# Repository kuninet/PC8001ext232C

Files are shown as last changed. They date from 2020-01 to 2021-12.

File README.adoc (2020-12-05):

= PC-8001用 外付けRS232Cボード =

== 概要 ==
* PC-8001の外部拡張バスへ接続する外付けRS232Cボードです。
** N-BASIC標準の PRINT%等のコマンドで動作することを目指します。
* シリアルLSI8251x2を搭載し、受信割り込みを使用します。

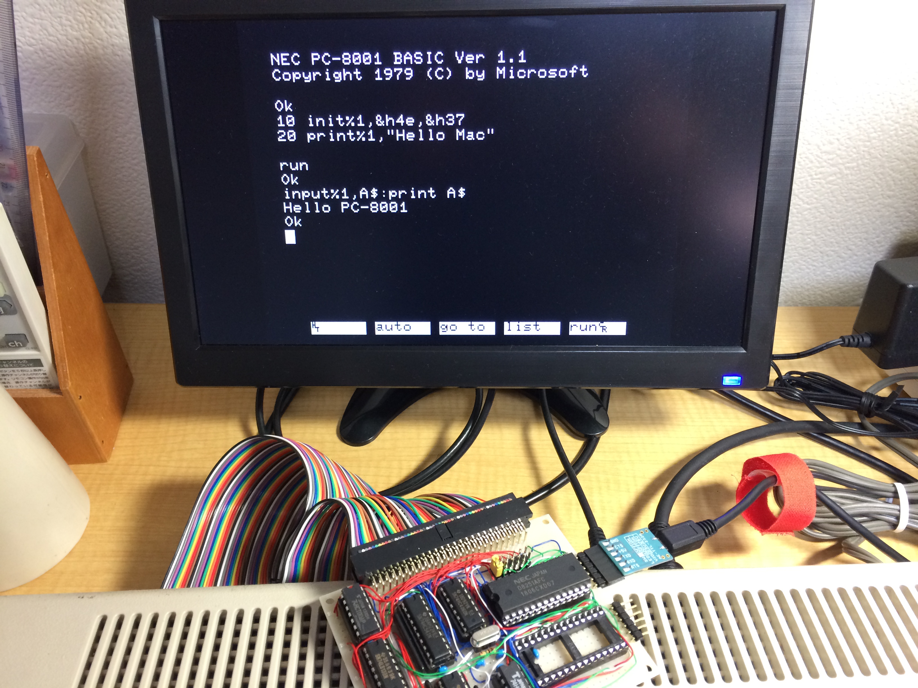
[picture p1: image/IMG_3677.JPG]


== I/Oアドレス == 
* シリアルIC 8251のI/Oアドレスは、PC-8001のPRINT%命令で動くように以下のようになっています。

.I/Oアドレス一覧
|===
|I/Oアドレス |用途 

|0C0H
|RS232C Ch1 8251データ入出力

|0C1H
|RS232C Ch1 8251コントロール入出力

|0C2H
|RS232C Ch2 8251データ入出力

|0C3H
|RS232C Ch2 8251コントロール入出力

|===

== 受信割り込みについて == 
* PC-8001はPC-8011/8012が接続された場合にモード2割り込みを使って割り込み処理をしています。割り込みベクタテーブルはPC-8001のRAM上に展開されています。
* シリアルIC 8251からの受信割り込みが発生した場合、ロジックICでモード2割り込みのベクタ08h、0Ahをデータバスに載せる仕組みを搭載しました。Z80 CPUは 8000hからの変位値として認識して 8008h、800Ah番地に格納されているRS232C処理アドレス(N-BASIC ROM内)へジャンプしてくれます。

.シリアル関係 割り込みアドレス一覧
|===
|割り込みベクタアドレス |用途 

|08008H
|RS232C Ch1 割り込みベクタ

|0800AH
|RS232C Ch2 割り込みベクタ

|===

== 参考URL == 
* Enriさんの ＰＣ－８００１ページ
** http://www43.tok2.com/home/cmpslv/Pc80/EnrPc.htm
* PC-8001 外付け232Cボード (BLOGで紹介した記事)
** https://kuninet.org/2020/01/25/pc-8001-%e5%a4%96%e4%bb%98%e3%81%91232c%e3%83%9c%e3%83%bc%e3%83%89/

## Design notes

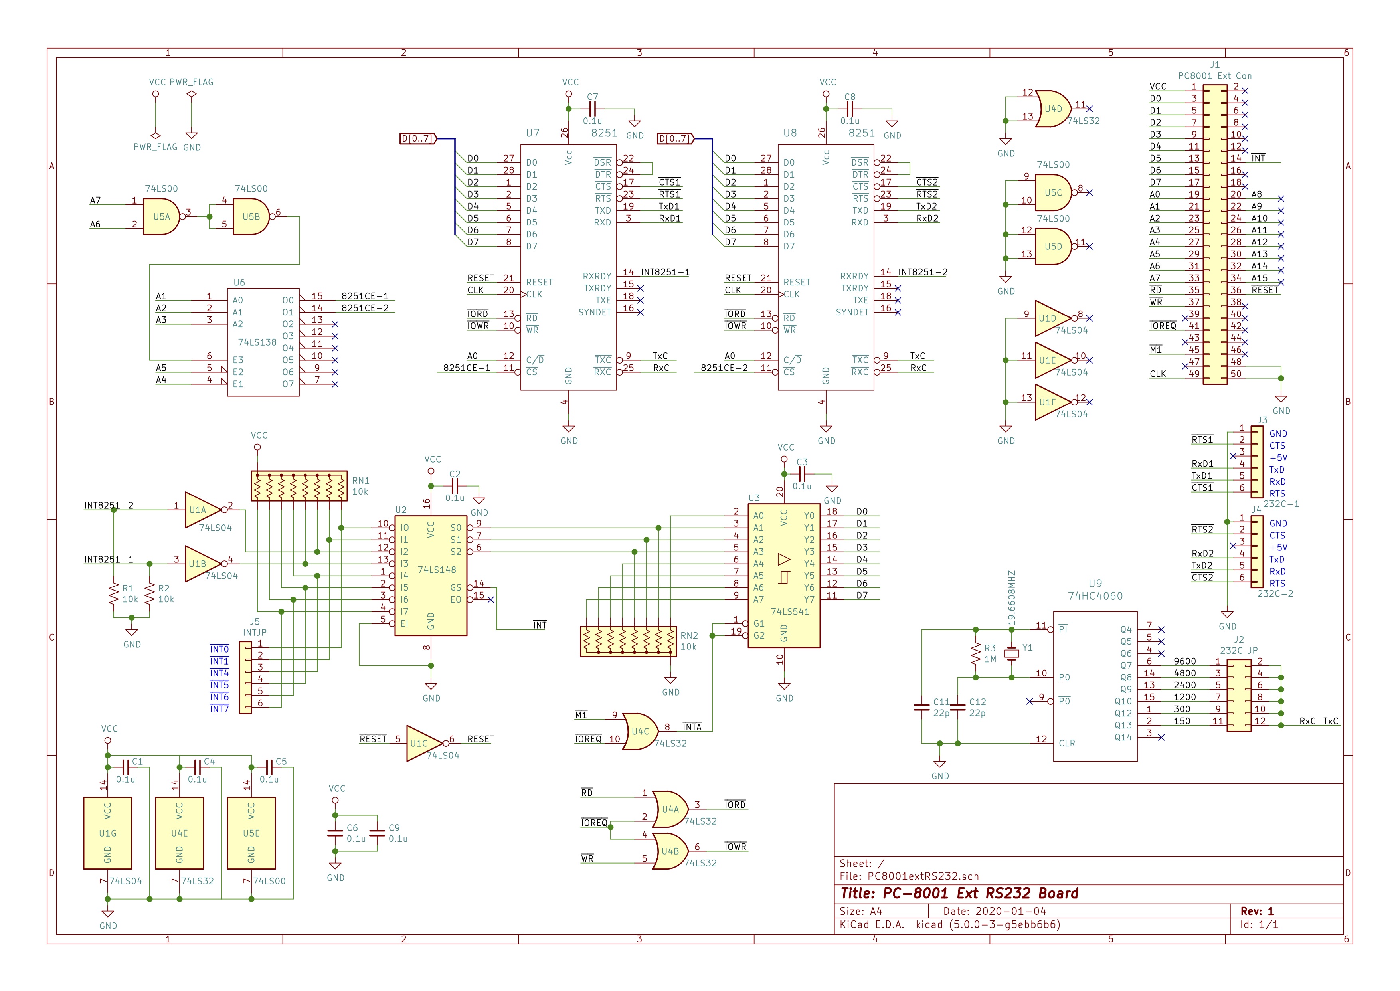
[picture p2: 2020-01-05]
image/PC8001extRS232.jpg

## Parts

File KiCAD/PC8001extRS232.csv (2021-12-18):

Reference | Value | Footprint | Datasheet
C1 | 0.1u | Capacitor_THT:C_Disc_D3.0mm_W1.6mm_P2.50mm | ~
C2 | 0.1u | Capacitor_THT:C_Disc_D3.0mm_W1.6mm_P2.50mm | ~
C3 | 0.1u | Capacitor_THT:C_Disc_D3.0mm_W1.6mm_P2.50mm | ~
C4 | 0.1u | Capacitor_THT:C_Disc_D3.0mm_W1.6mm_P2.50mm | ~
C5 | 0.1u | Capacitor_THT:C_Disc_D3.0mm_W1.6mm_P2.50mm | ~
C6 | 0.1u | Capacitor_THT:C_Disc_D3.0mm_W1.6mm_P2.50mm | ~
C7 | 0.1u | Capacitor_THT:C_Disc_D3.0mm_W1.6mm_P2.50mm | ~
C8 | 0.1u | Capacitor_THT:C_Disc_D3.0mm_W1.6mm_P2.50mm | ~
C9 | 0.1u | Capacitor_THT:C_Disc_D3.0mm_W1.6mm_P2.50mm | ~
C11 | 22p | Capacitor_THT:C_Disc_D3.0mm_W1.6mm_P2.50mm | ~
C12 | 22p | Capacitor_THT:C_Disc_D3.0mm_W1.6mm_P2.50mm | ~
H1 | MountingHole | MountingHole:MountingHole_3.2mm_M3 | ~
H2 | MountingHole | MountingHole:MountingHole_3.2mm_M3 | ~
H3 | MountingHole | MountingHole:MountingHole_3.2mm_M3 | ~
H4 | MountingHole | MountingHole:MountingHole_3.2mm_M3 | ~
J1 | PC8001 Ext Con | Connector_PinHeader_2.54mm:PinHeader_2x25_P2.54mm_Horizontal | ~
J2 | 232C JP | Connector_PinHeader_2.54mm:PinHeader_2x06_P2.54mm_Vertical | ~
J3 | 232C-1 | Connector_PinHeader_2.54mm:PinHeader_1x06_P2.54mm_Horizontal
J4 | 232C-2 | Connector_PinHeader_2.54mm:PinHeader_1x06_P2.54mm_Horizontal
J5 | INTJP | Connector_PinHeader_2.54mm:PinHeader_1x06_P2.54mm_Horizontal | ~
R1 | 10k | Resistor_THT:R_Axial_DIN0207_L6.3mm_D2.5mm_P10.16mm_Horizontal | ~
R2 | 10k | Resistor_THT:R_Axial_DIN0207_L6.3mm_D2.5mm_P10.16mm_Horizontal | ~
R3 | 1M | Resistor_THT:R_Axial_DIN0207_L6.3mm_D2.5mm_P10.16mm_Horizontal | ~
RN1 | 10k | Resistor_THT:R_Array_SIP9 | http://www.vishay.com/docs/31509/csc.pdf
RN2 | 10k | Resistor_THT:R_Array_SIP9 | http://www.vishay.com/docs/31509/csc.pdf
U1 | 74LS04 | Package_DIP:DIP-14_W7.62mm_Socket_LongPads | http://www.ti.com/lit/gpn/sn74LS04
U2 | 74LS148 | Package_DIP:DIP-16_W7.62mm_Socket_LongPads | http://www.ti.com/lit/gpn/sn74LS148
U3 | 74LS541 | Package_DIP:DIP-20_W7.62mm_Socket_LongPads | http://www.ti.com/lit/gpn/sn74LS541
U4 | 74LS32 | Package_DIP:DIP-14_W7.62mm_Socket_LongPads | http://www.ti.com/lit/gpn/sn74LS32
U5 | 74LS00 | Package_DIP:DIP-14_W7.62mm_Socket_LongPads | http://www.ti.com/lit/gpn/sn74ls00
U6 | 74LS138 | Package_DIP:DIP-16_W7.62mm_Socket_LongPads
U7 | 8251 | Package_DIP:DIP-28_W15.24mm_Socket_LongPads
U8 | 8251 | Package_DIP:DIP-28_W15.24mm_Socket_LongPads
U9 | 74HC4060 | Package_DIP:DIP-16_W7.62mm_Socket_LongPads
Y1 | 19.6608MHZ | Crystal:Crystal_HC49-U_Vertical | ~

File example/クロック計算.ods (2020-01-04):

 | kbps | bps
Q7 | 153.6 | 9600
Q8 | 76.8 | 4800
Q9 | 38.4 | 2400
Q10 | 19.2 | 1200
 | 9.6 | 600
Q12 | 4.8 | 300
Q13 | 2.4 | 150

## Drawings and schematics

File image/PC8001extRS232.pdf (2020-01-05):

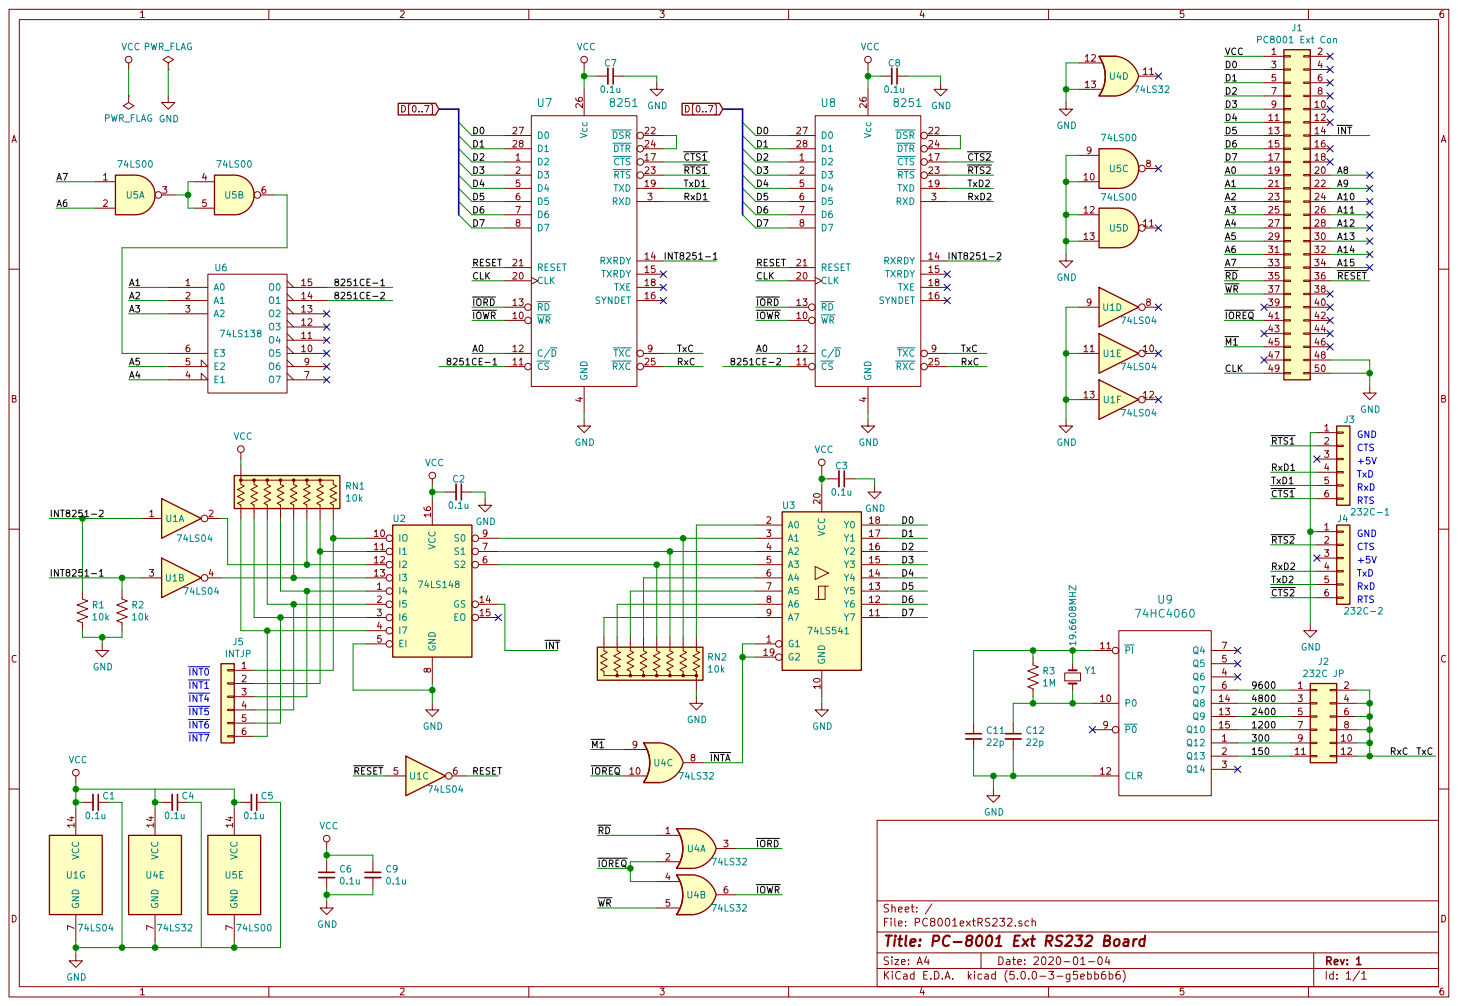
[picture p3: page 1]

4800 3 | 4
2400 5 | 6
1200 7 | 8
300 9 | 10

File: PC8001extRS232.sch Sheet: /
Id: 1/1 Title: PC-8001 Ext RS232 Board

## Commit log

2020-01-04 init commit
    [PC8001extRS232.kicad_pcb, PC8001extRS232.sch, クロック計算.ods]
2020-01-04 回路図 画像化
2020-01-05 アドレスデコーダ変更、割り込み回路のNOT削除
    [PC8001extRS232.sch]
2020-01-05 .gitignore 場所変更
2020-12-05 README若干追記
2021-12-18 プリント基板 REV1 ガーバー出力
    [PC8001extRS232.GBL, PC8001extRS232.GBO, PC8001extRS232.GBP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]
